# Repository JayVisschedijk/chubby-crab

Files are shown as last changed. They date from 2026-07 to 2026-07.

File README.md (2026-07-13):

# Chubby Crab (Colorlight Programmer)
A project to make programming the Colorlight 5A-75B a plug-and-play situation. It is built around the Adafruit FT232H.  
This programmer only fits on Colorlight 5A-75B versions 8.x

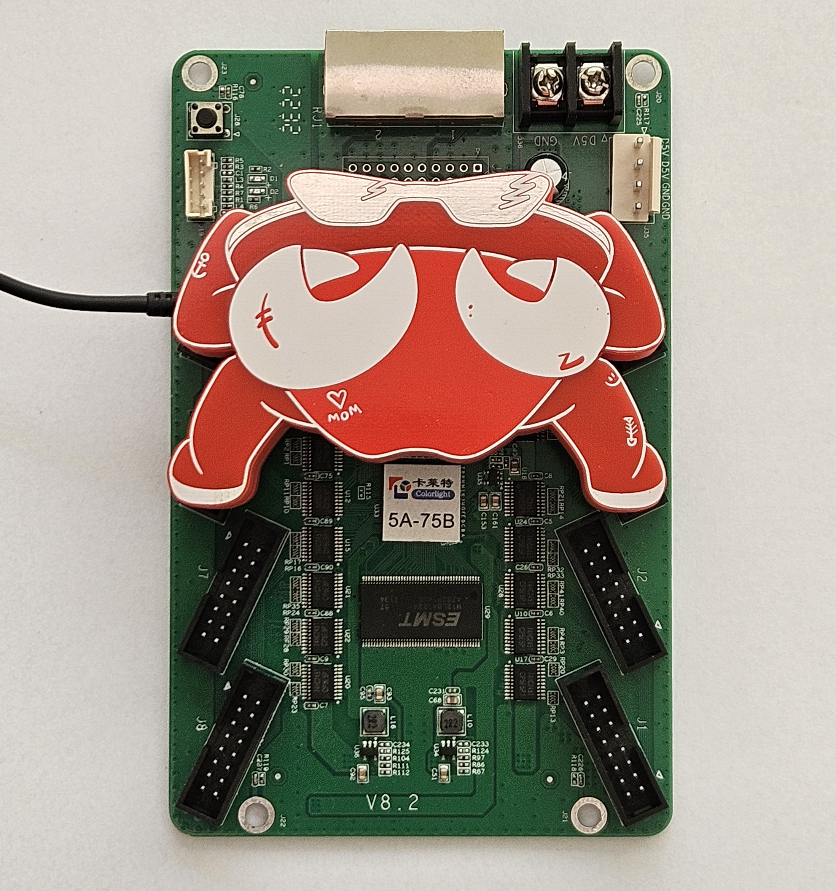
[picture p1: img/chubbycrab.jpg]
The Chubby Crab programmer mounted on a Colorlight.
[](./img/chubbycrab.jpg)

This project is inspired by the [q3k/chubby75](https://github.com/q3k/chubby75) project.  
Placement of the components is taken from [cyber-murmel/chubby-hat](https://github.com/cyber-murmel/chubby-hat). Thank you for doing the work of mapping the exact placements.

# How to use
*Note: if you're looking for a quick and easy way to flash just a few Colorlights, you might as well just use a JTAG programmer and connect it as explained in the [chubby75 documentation](https://github.com/q3k/chubby75/tree/master/5a-75b).*

Connect the Chubby Crab to the Colorlight by placing the 4 connectors (arms and legs) on Colorlight connectors J3, J4, J5, J6. When placed correctly, the pogo pins will connect to the JTAG, 3.3V, GND pads on the Colorlight.
When powering the Colorlight via the Chubby Crab (USB), set the slide switch to 3.3V. When powering the Colorlight with external 5V, set the slide switch to NC (Not Connected).

# Make your own
This repo contains all files to make your own Chubby Crab. Follow the steps from `./instructions.md` and you should end up with your own crab.
For those that skip instruction files: J7 parts are not included in the BOM, order separately.

## Room for improvement
This was just my first prototype and since it does what it must do, I can't be bothered (yet) to make a V2. But there's (quite some) room for improvement. Please open issues for ideas for improvement. If the list grows big enough, I might make a V2.

# License
This project is released under the MIT license.
Note that a part of this project was taken from the [cyber-murmel/chubby-hat](https://github.com/cyber-murmel/chubby-hat) project under [MIT License](https://github.com/cyber-murmel/chubby-hat/blob/main/LICENSE).

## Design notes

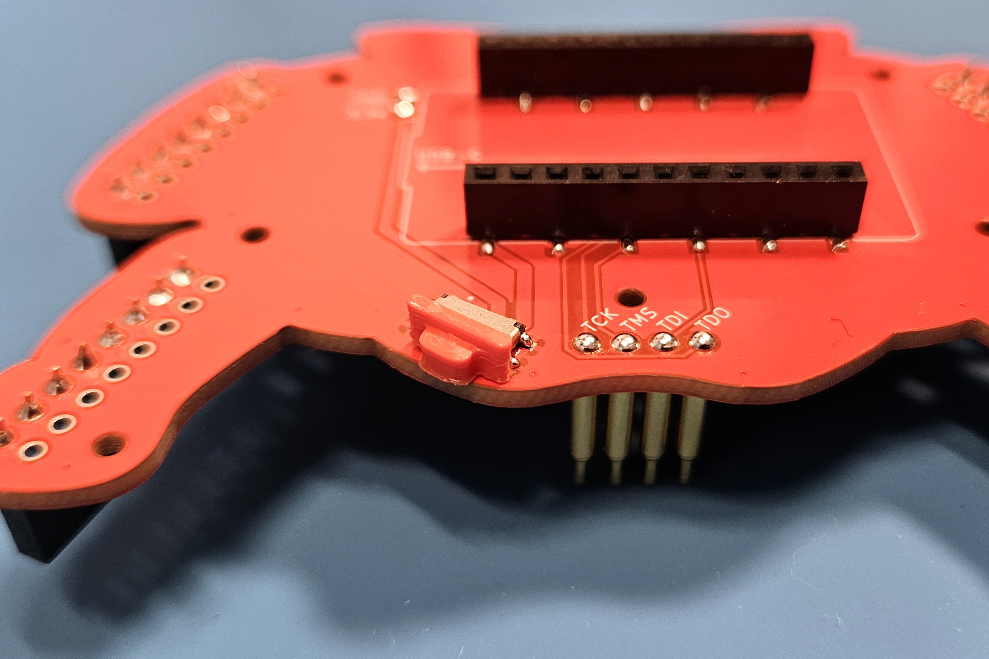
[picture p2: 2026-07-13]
img/switch-cap.jpg

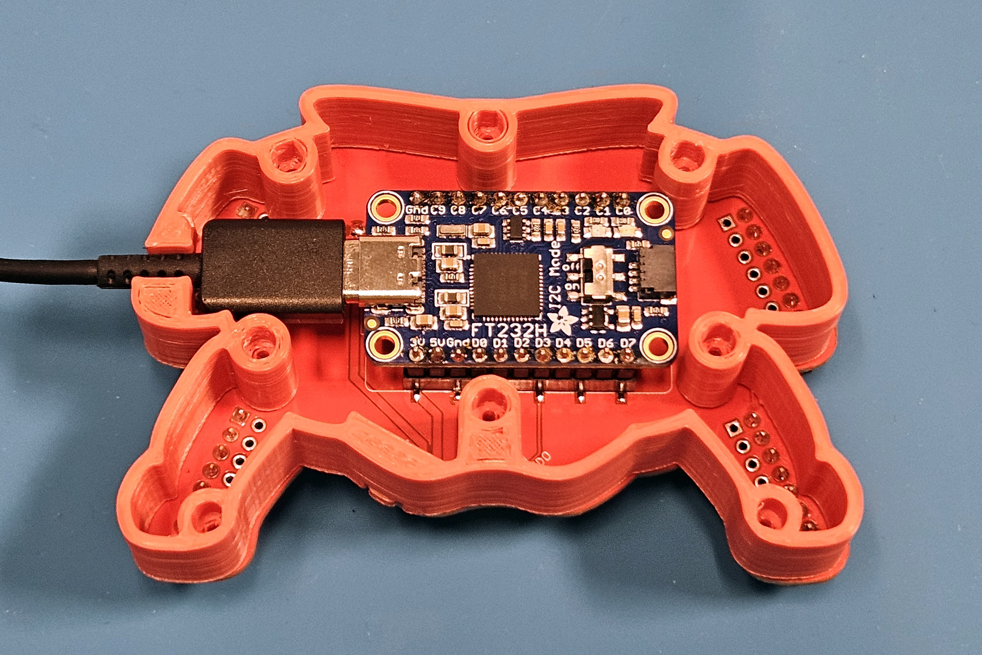
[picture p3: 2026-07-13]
img/inside.jpg

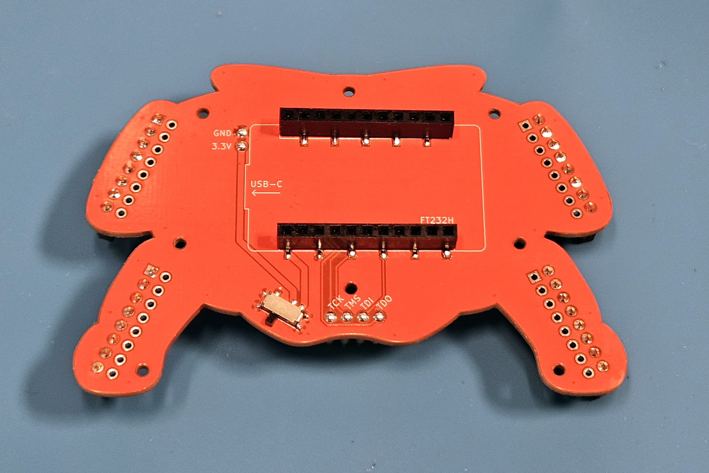
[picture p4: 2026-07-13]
img/base-front.jpg

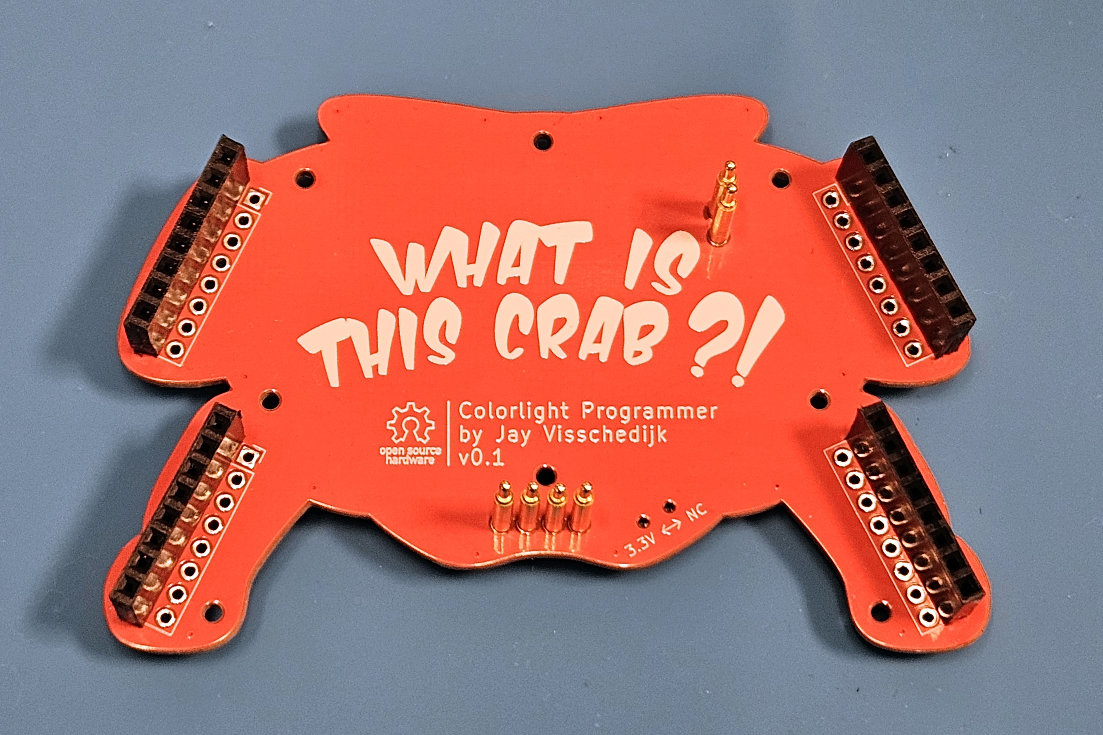
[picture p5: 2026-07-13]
img/base-back.jpg

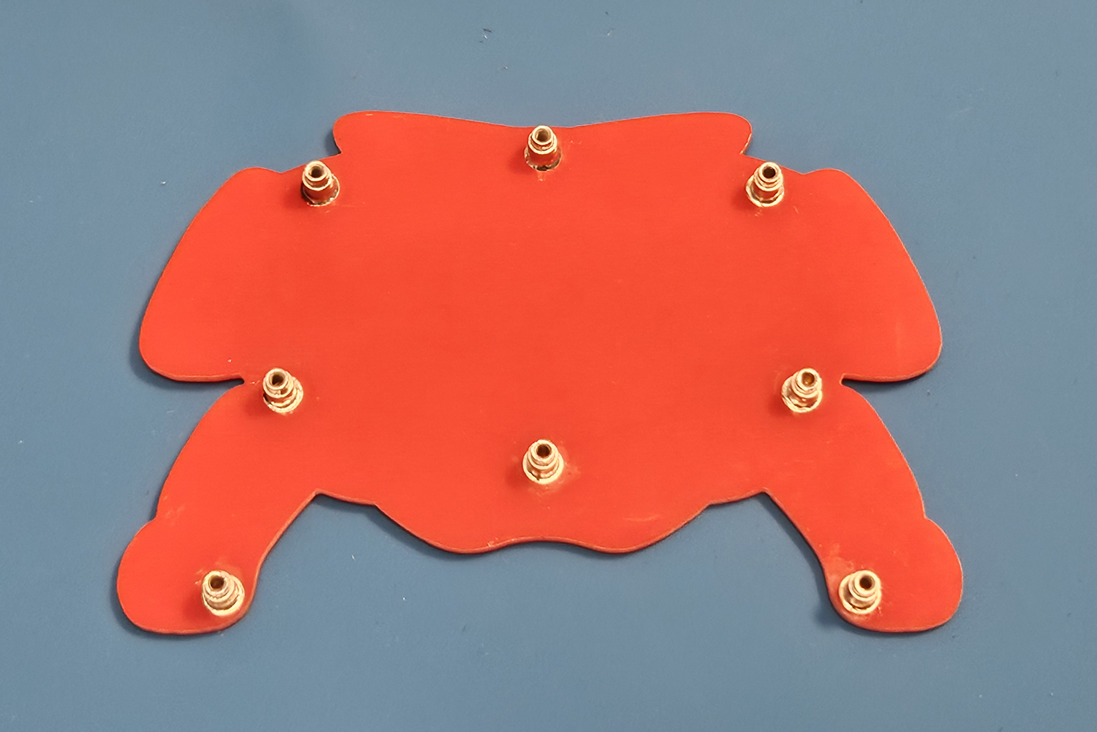
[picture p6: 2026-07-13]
img/cover-back.jpg

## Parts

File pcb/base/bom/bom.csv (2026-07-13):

Designator | Footprint | Qty | Value | LCSC Part #
J1,J2,J3,J4,J5,J6 | ChubbyCrab:PogoPin_0.9mm_ThroughHole | 6 | Conn_01x01_Pin | C7471744
J8,J9,J10,J11 | Connector_PinSocket_2.54mm:PinSocket_2x08_P2.54mm_Vertical | 4 | Conn_02x08 | C30734
S1 | ChubbyCrab:SW_MSK12C02 | 1 | MK-12C02-G020 | C963206

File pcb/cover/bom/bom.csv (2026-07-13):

Designator | Footprint | Qty | Value | LCSC Part #
H1,H2,H3,H4,H5,H6,H7,H8 | ChubbyCrab:Standoff_4.2mm_SMD | 8 | Standoff | C5301795

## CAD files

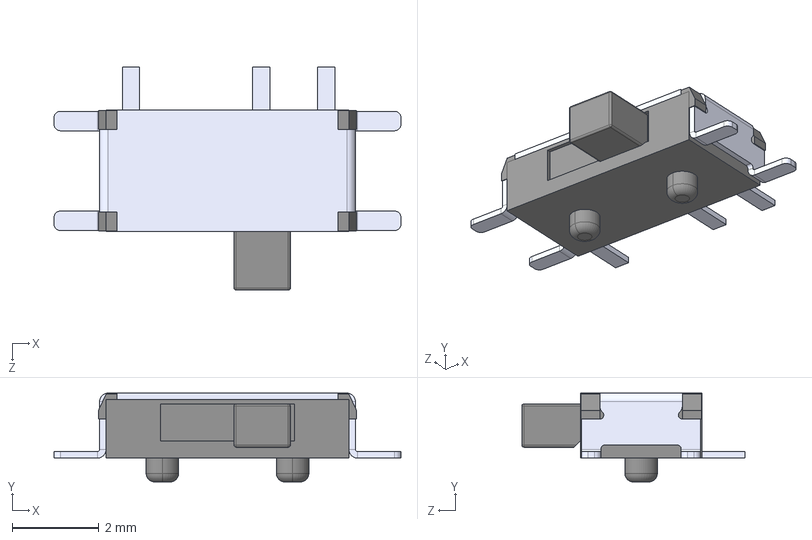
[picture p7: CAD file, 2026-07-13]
pcb/base/kicad/custom_library/3d_models/MSK12C02.step
8.00 x 2.05 x 5.15 mm

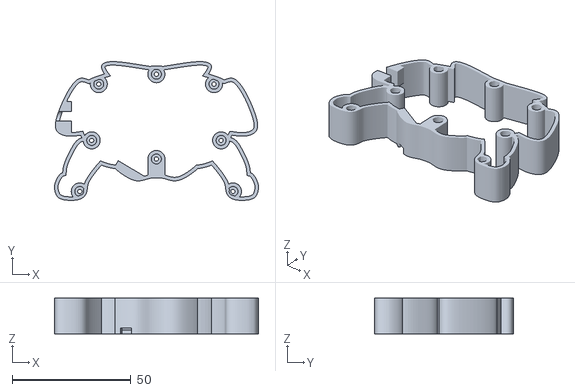
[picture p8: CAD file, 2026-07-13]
spacer/spacer.stl
85.9 x 58.4 x 15.0

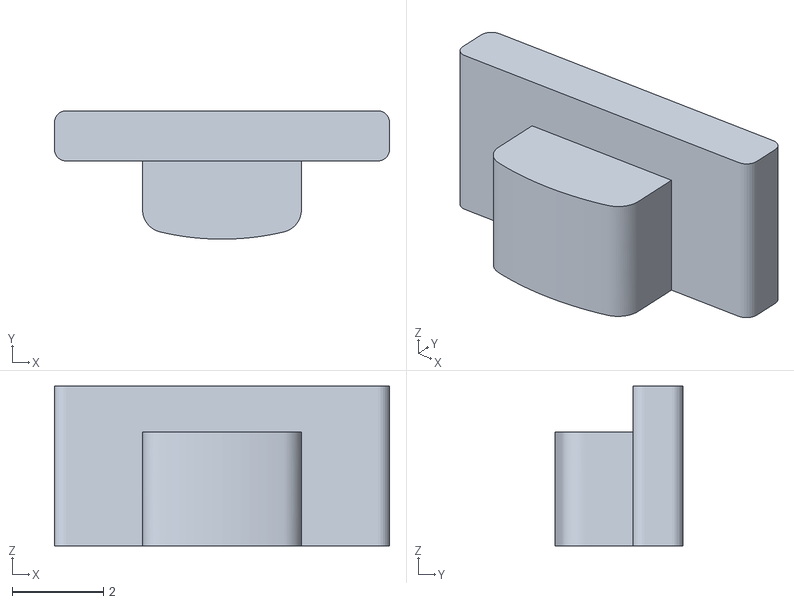
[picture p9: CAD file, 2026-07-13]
spacer/switch-cap.stl
7.35 x 2.82 x 3.50

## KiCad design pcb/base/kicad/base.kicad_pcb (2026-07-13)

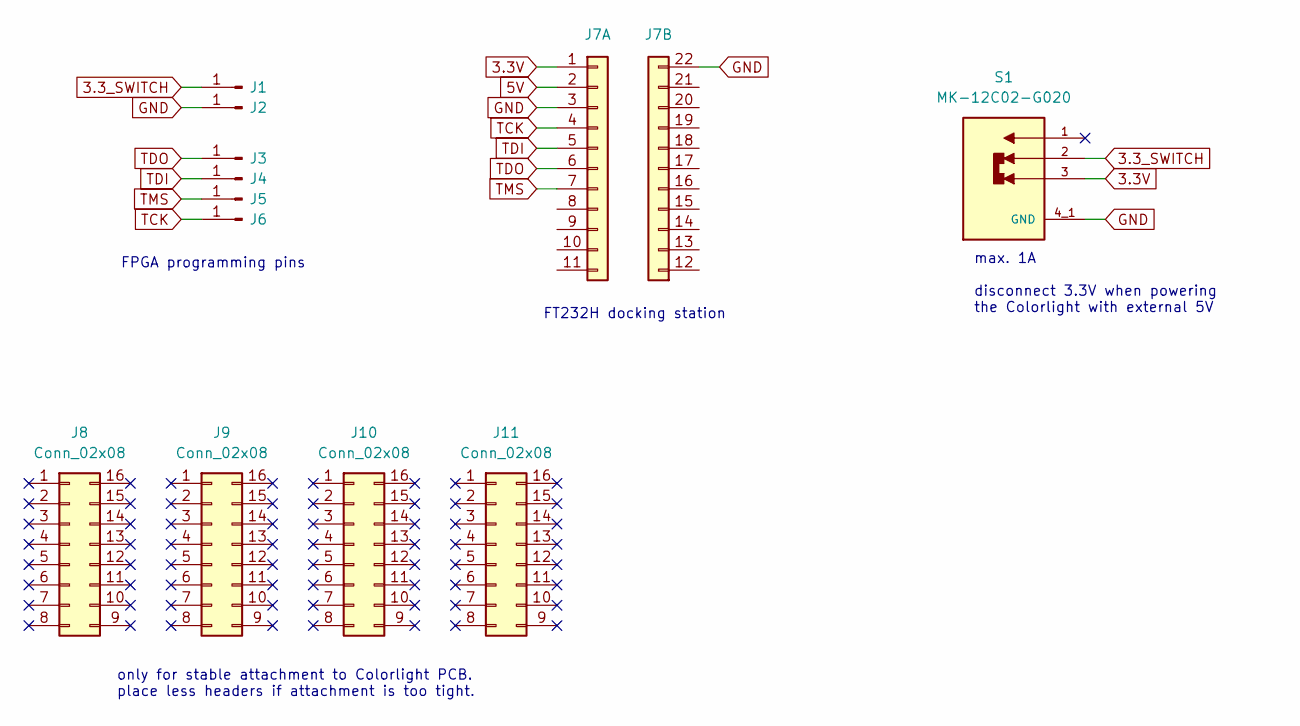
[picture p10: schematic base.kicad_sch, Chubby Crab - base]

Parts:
J1, J2, J3, J4, J5, J6: Conn_01x01_Pin; PogoPin_0.9mm_ThroughHole; LCSC Part # C7471744
J7: FT232H_2x11_P2.54mm
J8, J9, J10, J11: Conn_02x08; PinSocket_2x08_P2.54mm_Vertical; LCSC Part # C30734
S1: MK-12C02-G020; SW_MSK12C02; Mf. Part # MK-12C02-G020; LCSC Part # C963206

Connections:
3.3V: J7.1, S1.3
3.3_SWITCH: J1.1, S1.2
5V: J7.2
GND: J2.1, J7.3, J7.22, S1.4_1 (GND), S1.4_2 (GND), S1.4_3 (GND), S1.4_4 (GND)
TCK: J6.1, J7.4
TDI: J4.1, J7.5
TDO: J3.1, J7.6
TMS: J5.1, J7.7

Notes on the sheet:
only for stable attachment to Colorlight PCB. place less headers if attachment is too tight.
max. 1A disconnect 3.3V when powering the Colorlight with external 5V
FPGA programming pins
FT232H docking station

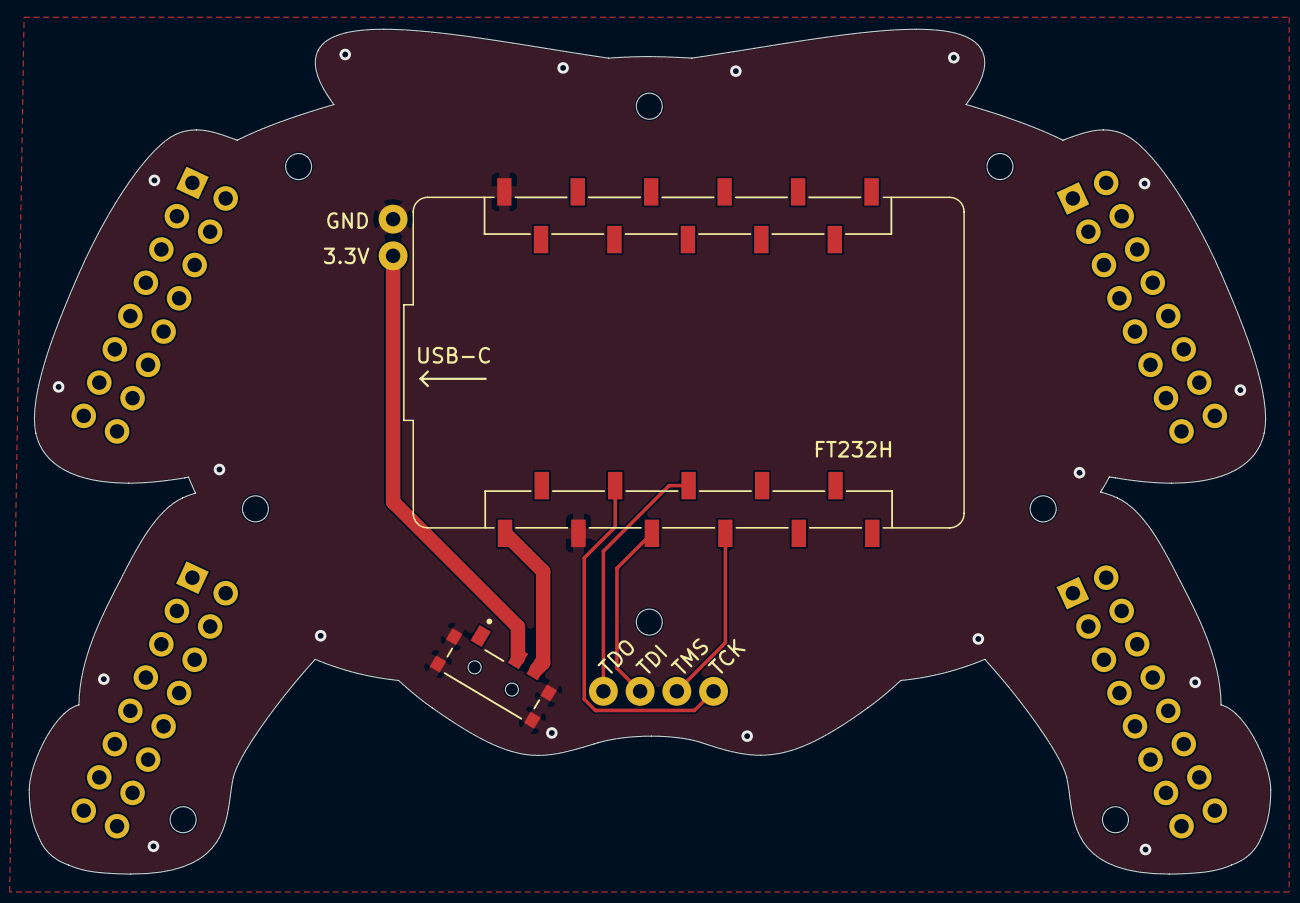
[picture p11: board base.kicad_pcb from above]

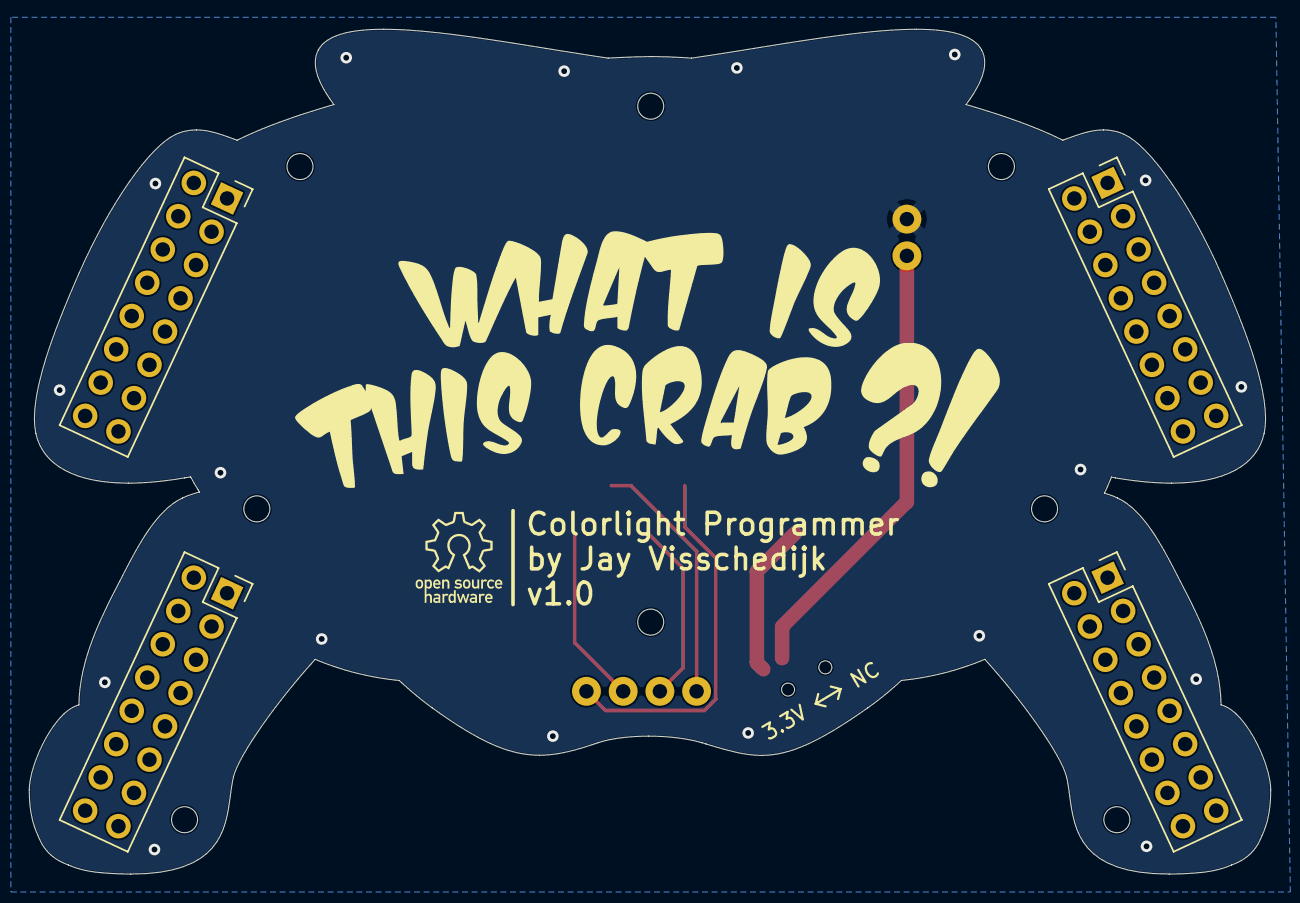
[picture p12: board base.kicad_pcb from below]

Board: 2 copper layers, 85.9 x 58.4 mm, 20 parts (18 on the bottom side), 7 nets.

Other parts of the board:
H1, H2, H3, H4, H5, H6, H7, H8: MountingHole; MountingHole_1.8mm_M1.6

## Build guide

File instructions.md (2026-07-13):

*Note: the PCB in the pictures shows the wrong JTAG pinout notation. This is fixed in V1.0*

# Order PCBs
Gerber files: `./pcb/{base,cover}/gerber`  
Bill of Material: `./pcb/{base,cover}/bom`  
Pick & Place file: `./pcb/{base,cover}/cpl`  

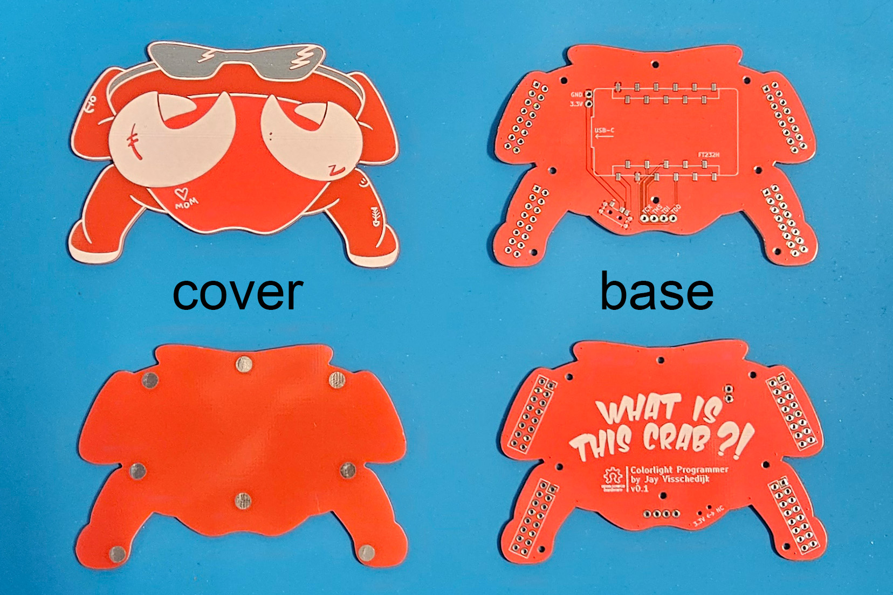
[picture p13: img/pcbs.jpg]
Overview of the frontside and backside of the cover and base PCBs.
[](./img/pcbs.jpg)

# Components
The two Bills of Material contain all components you need for one Chubby Crab.  
For hand soldering: Order those components on LCSC. Find all components quickly by uploading the Bill of Material in the search bar.  
For PCB Assembly: LCSC part numbers are listed for PCB assembly by JLCPCB. The only component I couldn't find on LCSC were 1x11P 2.54 female connectors, 5mm heigth and SMD, staggered pins. You need to order those separately. If you find those on LCSC, please let me know.  
The parts below should be ordered separately and are not included on the Bill of Material.  
You also need a USB-C cable. The cable should have a connector of ≤17mm long (excl. inserted part), or you need to adjust the strain relief part of the spacer. (Sorry! It's on the improvements list.)

| Part | Qty | URL |
| --- | --- | --- |
| Female Header, PH5, Single Row type 1 or 2, 1x11P | 2 | https://aliexpress.com/item/1005006319376319.html |
| Screws, M1.6 * 16mm | 8 | https://aliexpress.com/item/1005006674159703.html |
| Adafruit FT232H | 1 | https://www.adafruit.com/product/2264 |

Instead of using 2x8P headers (C30734, J8-J11), I just cut 1x8 pieces from a long header strip.

# Hand-soldering PCBs
1. Solder the 2 connectors and slide switch on the frontside of the base PCB. [picture](./img/base-front.jpg)
2. Place the 4 mounting connectors on the backside of the base PCB. Two single rows will also suffice. [picture](./img/base-back.jpg)
3. Place the 6 pogo pins. When done, place the PCB on a Colorlight and see if the pogo pins touch the JTAG/3.3V/GND pins. If not, leave the PCB on the Colorlight, heat up the solder joint and adjust the pin until it is correct. [(same) picture](./img/base-back.jpg)
4. Place the 8 standoffs on the backside of the cover PCB, big side down. Try to place them *perfectly* in the center of the pad, since I left no room for adjustments. (Sorry! Again, it's on the list..) Try not to fill up the standoff with solder and block the way for the screws to be inserted. If you're using tweezers, realize that the tweezers absorb heat. Make sure to heat up the pad + standoffs before positioning it with the tweezers. [picture](./img/cover-back.jpg)

# Print spacer
STL files: `./spacer`

Best printed with a 0.2 nozzle.

# Assemble the Chubby Crab
1. Check if the switch cap fits on the slide switch. If not, adjust print or shape it with a knife until it fits. [picture](./img/switch-cap.jpg)
2. Check if the switch cap slides back and forth inside the spacer. If not, take the excess filament off with a knife until it slides. Especially the brim can cause friction.
3. Make sure the screws fit through the holes in the spacer. If not, drill them out.
4. Place the spacer + switch cap on the base PCB.
5. Connect the USB-C cable to the FT232H and place it in the sockets. Push the USB-C cable firmly into the spacer. [picture](./img/inside.jpg)
6. Place the cover on top and screw it closed. This is probably the moment you find out some of the standoffs are not aligned perfectly. Luckily, just a few screws are needed to keep everything together. If you get 2-4 screws in on strategic places, your crab will live. [picture](./img/assembled.jpg)

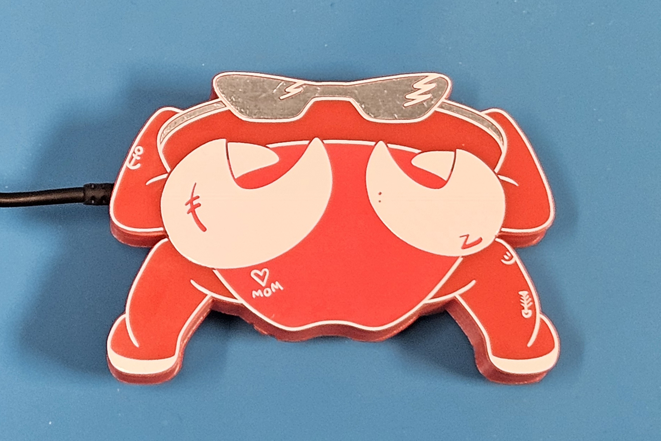
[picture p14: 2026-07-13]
img/assembled.jpg
